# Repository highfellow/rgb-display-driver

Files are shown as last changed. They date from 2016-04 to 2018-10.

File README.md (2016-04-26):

rgb-display-driver
==================

This is a project to make an open hardware display driver for 12v RGB LED strips, with various nice effects including a sound to light mode (colour organ). It is still very much work in progress, so don't expect that it will be usable for any particular purpose at the moment. I've mostly finished designing the electronics and testing them on breadboard, with circuit as shown in the KiCAD schematic. I'm just starting to work on laying out the PCB.

Below are some very rough instructions for compiling the software. I'll put up some better docs soon hopefully.

* The main arduino project is in the `code/` subdirectory.
* The `menu/` subdirectory contains a library which drives the LCD menu system. This needs to be symlinked to the libraries directory of your arduino sketchbook.
* The menu system is currently dependent on the Standard Template Library for Arduino released here: http://andybrown.me.uk/2011/01/15/the-standard-template-library-stl-for-avr-with-c-streams/ . Follow the instructions there to install this. You may need to make the patch described in this comment for it to compile. http://andybrown.me.uk/2011/01/15/the-standard-template-library-stl-for-avr-with-c-streams/#comment-2504271649 . At some point I may well rewrite the library to remove this dependency.

The `pcb/` subdirectory contains a couple of KiCAD projects - one for the main pcb and one for a smaller pcb with the controls attached.

The code files (menu and arduino project) are released under the GPL version 3: http://www.gnu.org/licenses/gpl-3.0.en.html . The KiCAD projects are released under the Creative Commons Attribution-ShareAlike license: http://creativecommons.org/licenses/by-sa/4.0/

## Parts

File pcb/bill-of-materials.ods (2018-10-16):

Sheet: main board bom
Reference Type | Quantity | Reference | Value | Footprint | Datasheet | Manufacturer | Product description | Product code | Supplier | Supplier code | Order | Supplier URL | Tolerance | Type | Notes
C | 1 | C24, | 4.7nF |  |  | Kemet | 4700pF 100V Ceramic Capacitor C0G, NP0 Radial 0.200" L x 0.125" W (5.08mm x 3.18mm) | C320C472J1G5TA | Digikey | 399-4302-ND | No | http://www.digikey.co.uk/product-search/en/capacitors/ceramic-capacitors/131083 | 5% | Ceramic
C | 3 | C22,C16,C14, | 10nF |  |  | Kemet | 10000pF 50V Ceramic Capacitor X7R Radial 0.150" L x 0.100" W (3.81mm x 2.54mm) | C315C103J5R5TA | Digikey | 399-9712-ND | No | http://www.digikey.co.uk/product-detail/en/kemet/C315C103J5R5TA/399-9712-ND/3725975 | 5% | Ceramic
C | 1 | C19, | 47nF |  |  | Kemet | 0.047µF 50V Ceramic Capacitor X7R Radial 0.200" L x 0.125" W (5.08mm x 3.18mm) | C320C473K5R5TA | Digikey | 399-4306-ND | No | http://www.digikey.co.uk/product-detail/en/kemet/C320C473K5R5TA/399-4306-ND/818082 | 10% | Ceramic
C | 8 | C2,C3,C4,C5,C11,C8,C10,C12, | 100nF |  |  | Kemet | 0.10µF 50V Ceramic Capacitor Z5U Radial 0.150" L x 0.100" W (3.81mm x 2.54mm) | C315C104M5U5TA | Digikey | 399-4151-ND | No | http://www.digikey.co.uk/product-detail/en/kemet/C315C104M5U5TA/399-4151-ND/817927 | 20% | Ceramic
C | 6 | C15,C18,C17,C27,C25,C23, | 100nF |  |  | Kemet | 0.10µF 50V Ceramic Capacitor X7R Radial 0.200" L x 0.125" W (5.08mm x 3.18mm) | C320C104J5R5TA | Digikey | 399-9775-ND | No | http://www.digikey.co.uk/product-detail/en/kemet/C320C104J5R5TA/399-9775-ND/3726074 | 10% | Ceramic
C | 2 | C6,C7, | 22pF |  |  | Kemet | 22pF 50V Ceramic Capacitor C0G, NP0 Radial 0.150" L x 0.100" W (3.81mm x 2.54mm) | C315C220J5G5TA | Digikey | 399-9721-ND | No | http://www.digikey.co.uk/product-detail/en/kemet/C315C220J5G5TA/399-9721-ND/3726111 | 20% | Ceramic
C | 3 | C26,C20,C21, | 1uF |  |  | Kemet | 1µF 25V Ceramic Capacitor X7R Radial 0.150" L x 0.100" W (3.81mm x 2.54mm) | C315C105K3R5TA | Digikey | 399-9714-ND | No | http://www.digikey.co.uk/product-search/en/capacitors/ceramic-capacitors/131083 | 10% | Ceramic
C | 3 | C1,C9,C13, | 10uF |  |  | Kemet | 10µF Conformal Coated Tantalum Capacitors 25V Radial 2.5 Ohm 0.217" Dia (5.50mm) | T350E106M025AT | Digikey | 399-9907-ND | No | http://www.digikey.co.uk/product-detail/en/kemet/T350E106M025AT/399-9907-ND/3726214 | 20% | Tantalum
D | 3 | D3,D2,D1, | DIODE-rgb |  |  | Fairchild Semiconductor | Diode Standard 100V 200mA Through Hole DO-35 | 1N4148 | Digikey | 1N4148FS-ND | No | http://www.digikey.co.uk/product-detail/en/fairchild-semiconductor/1N4148/1N4148FS-ND/458603
F | 1 | F1, | FUSE |  |  | Littelfuse Inc. | Fuse Block 15A 600V 1 Circuit Cartridge PCB | 03540101ZXGY | Digikey | F1498-ND | No | http://www.digikey.co.uk/product-detail/en/littelfuse-inc/03540101ZXGY/F1498-ND/553974
IC | 1 | IC1, | ATMEGA328-P | DIL28 |  | Arduino | AT-MEGA 328-P microcontroller | A000048 | Digikey | 1050-1019-ND | No | http://www.digikey.co.uk/product-search/en/integrated-circuits-ics/embedded-microcontrollers/2556109
J | 2 | J6,J7, | AUDIO_JACK |  |  | CUI Inc | 3.50mm (0.141" 1/8" Mini Plug) - Headphone Phone Jack Stereo Connector Solder | SJ1-3523NG | Digikey | CP1-3523NG-ND | No | http://www.digikey.co.uk/product-detail/en/cui-inc/SJ1-3523NG/CP1-3523NG-ND/738692
J | 1 | J4, | CONTROL_HEADER |  |  | On Shore Technology Inc. | 10 Positions Header, Shrouded Connector 0.100" (2.54mm) Through Hole Gold | 302-S101 | Digikey | ED1543-ND | No | http://www.digikey.co.uk/product-detail/en/on-shore-technology-inc/302-S101/ED1543-ND/2178422
J | 1 | J5, | LCD_HEADER |  |  | On Shore Technology Inc. | 14 Positions Header, Shrouded Connector 0.100" (2.54mm) Through Hole Gold | 302-S141 | Digikey | ED10522-ND | No | http://www.digikey.co.uk/product-detail/en/on-shore-technology-inc/302-S141/ED10522-ND/2794233
J | 1 | J2, | LED_CONNECTOR |  |  | CUI Inc. | 6 Position Circular Connector Receptacle, Female Sockets Solder Silver | MD-60S | Digikey | CP-2460-ND | No | http://www.digikey.co.uk/product-detail/en/cui-inc/MD-60S/CP-2460-ND/145311 |  |  | Rated to 2A per conductor at 12V DC
J | 1 | J1, | PWR_IN |  |  | CUI Inc. | Power Barrel Connector Jack 2.50mm ID (0.098"), 5.50mm OD (0.217") Through Hole, Right Angle | PJ-082BH | Digikey UK | CP-082BHCT-ND | No | http://www.digikey.co.uk/product-detail/en/cui-inc/PJ-082BH/CP-082BHCT-ND/3102547
J | 1 | J3, | UART_HEADER |  |  | Phoenix Contact | 5 Position Terminal Block Header, Male Pins, Unshrouded 0.138" (3.50mm) Vertical Through Hole | 1945122 | Digikey | 277-1752-ND | No | http://www.digikey.co.uk/product-detail/en/phoenix-contact/1945122/277-1752-ND/950880
Q | 3 | Q1,Q2,Q3, | IRL510PBF |  |  | Vishay Siliconix | MOSFET N-CH 100V 5.6A TO-220AB | IRL510PBF | Digikey | IRL510PBF-ND | No | http://www.digikey.co.uk/product-detail/en/vishay-siliconix/IRL510PBF/IRL510PBF-ND/811698
Q | 1 | Q4, | TP0606 |  |  | Microchip Technology | MOSFET P-CH 60V 320MA TO92-3 | TP0606N3-G | Digikey | TP0606N3-G-ND | No | http://www.digikey.co.uk/product-detail/en/microchip-technology/TP0606N3-G/TP0606N3-G-ND/4902382
R | 2 | R6,R7, | 1M |  |  | Stackpole Electronics Inc. | RES 1M OHM 1/8W 5% CARBON FILM | CF18JT1M00 | Digikey | CF18JT1M00TR-ND | No | http://www.digikey.co.uk/product-detail/en/stackpole-electronics-inc/CF18JT1M00/CF18JT1M00TR-ND/1741614
R | 1 | R5, | 20R |  |  | Stackpole Electronics Inc. | RES 20 OHM 1/2W 5% CARBON FILM | CF12JT20R0 | Digikey | CF12JT20R0CT-ND | No | http://www.digikey.co.uk/product-detail/en/stackpole-electronics-inc/CF12JT20R0/CF12JT20R0CT-ND/1830451 | 5%
R | 2 | R4,R3, | 20R |  |  | Stackpole Electronics Inc. | METAL FILM 0.125W 5% 22 OHM | CF18JT22R0 | Digikey | CF18JT22R0CT-ND | No | http://www.digikey.co.uk/product-detail/en/stackpole-electronics-inc/CF18JT22R0/CF18JT22R0CT-ND/2022702 | 1%
R | 1 | R2, | 135R |  |  | Stackpole Electronics Inc. | METAL FILM 0.125W 5% 130 OHM | CF18JT130R | Digikey | CF18JT130RCT-ND | No | http://www.digikey.co.uk/product-detail/en/stackpole-electronics-inc/CF18JT130R/CF18JT130RCT-ND/2022721 | 5%
R | 3 | R30,R23,R20, | 180R |  |  | Stackpole Electronics Inc. | RES 180 OHM 1/8W 5% CF AXIAL | CF18JT180R | Digikey | CF18JT180RCT-ND | No | http://www.digikey.co.uk/product-detail/en/stackpole-electronics-inc/CF18JT180R/CF18JT180RCT-ND/2022724
R | 3 | R29,R22,R19, | 2.2k |  |  | Stackpole Electronics Inc. | RES 2.2K OHM 1/8W 5% CF AXIAL | CF18JT2K20 | Digikey | CF18JT2K20CT-ND | No | http://www.digikey.co.uk/product-detail/en/stackpole-electronics-inc/CF18JT2K20/CF18JT2K20CT-ND/2022750
R | 1 | R17, | 3.9k |  |  | Stackpole Electronics Inc. | RES 3.9K OHM 1/8W 5% CARBON FILM | CF18JT3K90 | Digikey | CF18JT3K90CT-ND | No | http://www.digikey.co.uk/product-detail/en/stackpole-electronics-inc/CF18JT3K90/CF18JT3K90CT-ND/2022756
R | 2 | R18,R14, | 8.2k |  |  | Stackpole Electronics Inc. | RES 8.2K OHM 1/8W 5% CF AXIAL | CF18JT8K20 | Digikey | CF18JT8K20CT-ND | No | http://www.digikey.co.uk/product-detail/en/stackpole-electronics-inc/CF18JT8K20/CF18JT8K20CT-ND/2022764
R | 5 | R1,R8,R9,R10,R11, | 10k |  |  | Stackpole Electronics Inc. | RES 10K OHM 1/8W 5% CF AXIAL | CF18JT10K0 | Digikey | CF18JT10K0CT-ND | No | http://www.digikey.co.uk/product-detail/en/stackpole-electronics-inc/CF18JT10K0/CF18JT10K0CT-ND/2022766
R | 5 | R21,R26,R15,R13,R16, | 18k |  |  | Stackpole Electronics Inc. | RES 18K OHM 1/8W 5% CF AXIAL | CF18JT18K0 | Digikey | CF18JT18K0CT-ND | No | http://www.digikey.co.uk/product-search/en/resistors/through-hole-resistors/66690
R | 3 | R31,R25,R24, | 22k |  |  | Stackpole Electronics Inc. | RES 22K OHM 1/8W 5% CF AXIAL | CF18JT22K0 | Digikey | CF18JT22K0CT-ND | No | http://www.digikey.co.uk/product-detail/en/stackpole-electronics-inc/CF18JT22K0/CF18JT22K0CT-ND/2022774
R | 1 | R12, | 33k |  |  | Stackpole Electronics Inc. | RES 33K OHM 1/8W 5% CF AXIAL | CF18JT33K0 | Digikey | CF18JT33K0CT-ND | No | http://www.digikey.co.uk/product-detail/en/stackpole-electronics-inc/CF18JT33K0/CF18JT33K0CT-ND/2022778
R | 3 | R32,R28,R27, | 330k |  |  | Stackpole Electronics Inc. | RES 330K OHM 1/8W 5% CF AXIAL | CF18JT330K | Digikey | CF18JT330KCT-ND | No | http://www.digikey.co.uk/product-detail/en/stackpole-electronics-inc/CF18JT330K/CF18JT330KCT-ND/2022802
RV | 2 | RV3,RV2, | 50R |  |  | Bourns Inc. | 50 Ohm 0.5W, 1/2W PC Pins Through Hole Trimmer Potentiometer Cermet 1 Turn Top Adjustment | 3362P-1-500LF | Digikey | 3362P-1-500LF-ND | No | http://www.digikey.co.uk/product-detail/en/bourns-inc/3362P-1-500LF/3362P-1-500LF-ND/2536639
RV | 2 | RV1,RV4, | 10k |  |  | Bourns Inc. | 10k Ohm 0.5W, 1/2W PC Pins Through Hole Trimmer Potentiometer Cermet 1 Turn Top Adjustment | 3362P-1-103LF | Digikey | 3362P-103LF-ND | No | http://www.digikey.co.uk/product-detail/en/bourns-inc/3362P-1-103LF/3362P-103LF-ND/1088412
SW | 1 | SW1, | SW_POWER |  |  | C&K Components | Rocker Switch SPDT 7.5A (AC/DC) 125V Through Hole, Right Angle | E101J1AQE2 | Digikey | CKN2070-ND | No | http://www.digikey.co.uk/product-detail/en/c-k-components/E101J1AQE2/CKN2070-ND/484024
U | 4 | U2,U3,U5,U4, | LM358_BIG |  |  | Texas Instruments | General Purpose Amplifier 2 Circuit 8-PDIP | LM358P | Digikey | 296-1395-5-ND | No | http://www.digikey.co.uk/product-detail/en/texas-instruments/LM358P/296-1395-5-ND/277042
U | 1 | U1, | 7805_NUM |  |  | ON Semiconductor | Linear Voltage Regulator IC Positive Fixed 1 Output 5V 1A TO-220AB | NCP7805TG | Digikey | NCP7805TGOS-ND | No | http://www.digikey.co.uk/product-detail/en/on-semiconductor/NCP7805TG/NCP7805TGOS-ND/2271529
X | 1 | X1, | 16MHz |  |  | TXC CORPORATION | 16MHz ±10ppm Crystal 18pF 30 Ohm -20°C ~ 70°C Through Hole HC49/US | 9B-16.000MEEJ-B | Digikey | 887-1244-ND | No | http://www.digikey.co.uk/product-detail/en/txc-corporation/9B-16.000MEEJ-B/887-1244-ND/2207664

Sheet: controls board bom
Reference Type | Quantity | Reference | Value | Footprint | Datasheet | Manufacturer | Product description | Product code | Supplier | Supplier code | Order | Supplier URL
D | 1 | D1, | LED_RABG |  |  | Adafruit Industries LLC | Red, Green, Blue (RGB) LED Indication - Discrete 2.1V Red, 3.8V Green, 2.7V Blue 4-DIP (0.200" 5.08mm) | 314 | Digikey | 1528-1127-ND | No | http://www.digikey.co.uk/product-detail/en/adafruit-industries-llc/314/1528-1127-ND/5353587
J | 1 | J1, | CONTROLS_HEADER |  |  | On Shore Technology Inc. | 10 Positions Header, Shrouded Connector 0.100" (2.54mm) Through Hole Gold | 302-S101 | Digikey | ED1543-ND | No | http://www.digikey.co.uk/product-detail/en/on-shore-technology-inc/302-S101/ED1543-ND/2178422
J | 1 | J2, | ENCODER |  |  | TT Electronics/BI | ENCODER 12MM ROTARY TOP ADJUST | EN12-HN22AF25 | Digikey | 987-1399-ND | No | http://www.digikey.co.uk/product-detail/en/tt-electronics-bi/EN12-HN22AF25/987-1399-ND/2620668
SW | 1 | SW2, | MODE BUTTON |  |  | C&K Components | Pushbutton Switch SPST-NO Keyswitch Through Hole | D6R40 F1 LFS | Digikey | 401-1975-ND | No | http://www.digikey.co.uk/product-detail/en/c-k-components/D6R40-F1-LFS/401-1975-ND/1466332
SW | 1 | SW1, | PARAM BUTTON |  |  | C&K Components | Pushbutton Switch SPST-NO Keyswitch Through Hole | D6R50 F1 LFS | Digikey | 401-1976-ND | No | http://www.digikey.co.uk/product-detail/en/c-k-components/D6R50-F1-LFS/401-1976-ND/1466333

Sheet: extra parts
Extra parts – i.e. parts not on PCB but needed for assembly
Description | Quantity | Manufacturer | Product Code | Supplier | Supplier Code | URL
FUSE GLASS 7.5A 32VAC/VDC 3AB | 1 | Littelfuse Inc. | 0AGC07.5V | Digikey | F5024-ND | http://www.digikey.co.uk/product-detail/en/littelfuse-inc/0AGC07.5V/F5024-ND/2519098
6 Position Circular Connector Plug, Male Pins Solder, Crimp Pin Adapter Available Silver | 2 | CUI Inc. | MD-60 | Digikey | CP-2060-ND | http://www.digikey.co.uk/product-detail/en/cui-inc/MD-60/CP-2060-ND/96916
10 Position Rectangular Socket Connector IDC Gold | 2 | On Shore Technology Inc. | 101-106 | Digikey | ED10500-ND | http://www.digikey.co.uk/product-detail/en/on-shore-technology-inc/101-106/ED10500-ND/2794212
14 Position Rectangular Socket Connector IDC Gold | 1 | On Shore Technology Inc. | 101-146 | Digikey | ED10501-ND | http://www.digikey.co.uk/product-detail/en/on-shore-technology-inc/101-146/ED10501-ND/2794213
KNOB KNURLED 0.750" METAL | 1 | Kilo International | OEJNI-75-4-7 | Digikey | 226-4239-ND | http://www.digikey.co.uk/product-detail/en/kilo-international/OEJNI-75-4-7/226-4239-ND/5970395
Flat Ribbon Cable Gray 14 Conductors 0.050" (1.27mm) Flat Cable 5.0' (1.52m) | 1 | 3M | 3365/14 300SF | Digikey | MC14G-5-ND | http://www.digikey.co.uk/product-detail/en/assmann-wsw-components/AWG28-14-G-300/AE14G-5-ND/686330
6 Position Circular Connector Receptacle, Female Sockets Solder Silver | 2 | CUI Inc. | MD-60SV | Digikey | CP-2760-ND | http://www.digikey.co.uk/product-detail/en/cui-inc/MD-60SV/CP-2760-ND/299895
12V 84W AC/DC External Desktop (Class I) Adapter Cord (Sold Separately) Input | 1 | Volgen America/Kaga Electronics USA | KTPS90-1207 | Digikey | 62-1186-ND | http://www.digikey.co.uk/product-detail/en/volgen-america-kaga-electronics-usa/KTPS90-1207/62-1186-ND/3024981

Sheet: old-bom
 | Value | Quantity | Refs | From (CPC / Farnell / Have) | Code
Main Board | 22pF | 2 | C6 C7 | Have | -
 | 4.7nF | 1 | C25 | Farnell | 1100379
 | 10nF | 3 | C13 C16 C24 | Farnell | 2332955
 | 47nF | 1 | C17 | Farnell | 1457648
 | 100nF | 13 | C2 C3 C4 C5 C8 C9 C10 C11 C14 C15 C18 C19 C26 | Farnell | 2112751
 | 1uF | 5 | C21 C22 C23 C27 C28 | Farnell
 | 10uF | 3 | C1 C12 C20 | Farnell
 | DIODE | 3 | D1 D2 D3 | Farnell | 1700925
 | ATMEGA328-P | 1 | IC1 | Have | -
 | LED_HEADER | 1 | J2 | Farnell | 1593440
 | LCD_HEADER | 1 | J4 | Farnell | 1593429
 | CONTROL_HEADER | 1 | J5 | Farnell | 1593429
 | AUDIO_HEADER_OUT | 1 | J6 | Farnell | 1593412
 | AUDIO_HEADER_IN | 1 | J7 | Farnell | 1593412
 | PWR_IN | 1 | J1 | Farnell | 1593413
 | UART_HEADER | 1 | J3 | Farnell | 1593414
 | STP35NF10 | 3 | Q1 Q2 Q3 | Have | -
 | 3.9k | 2 | R10 R13 | Farnell | 9343156
 | 6.8k | 3 | R17 R18 R24 | Farnell | 9343466
 | 8.2k | 2 | R12 R14 | Farnell | 9343571
 | 10k | 7 | R1 R4 R5 R6 R7 | Farnell | 9342419
 | 15k | 4 | R9 R11 R19 R20 | Farnell | 9342630
 | 33k | 3 | R8 R22 R25 | Farnell | 9343059
 | 100k | 4 | R15 R16 R21 R23 | Farnell | 9342427
 | 1M | 2 | R2 R3 | Farnell | 9342435
 | 10k | 2 | RV1 RV2 | Farnell | 1227539
 | SW_POWER | 1 | SW1 | Farnell | 1437701
 | SW_PUSH | 1 | SW2 | Have | -
 | 7805 | 1 | U1 | Have | -
 | LM358 | 4 | U2 U3 U4 U5 | Farnell | 1211132
 | 16MHz | 1 | X1 | Have | -
Controls Board | CONTROLS_HEADER | 1 | J1 | Farnell | 1593429
 | ENCODER | 1 | J2
 | PARAM BUTTON | 1 | SW1
 | MODE BUTTON | 1 | SW2
Misc | DIP-28 socket | 1
 | Ribbon cable | 1 metre
 | 3x2 header socket | 3 |  | Farnell | 1593488
 | 3x1 header socket | 2 |  | Farnell | 1593459
 | 4x1 header socket | 1 |  | Farnell | 1593460
 | 5x1 header socket | 1 |  | Farnell | 1593461
 | 2.5mm screws | 100 |  | Farnell | 1420119

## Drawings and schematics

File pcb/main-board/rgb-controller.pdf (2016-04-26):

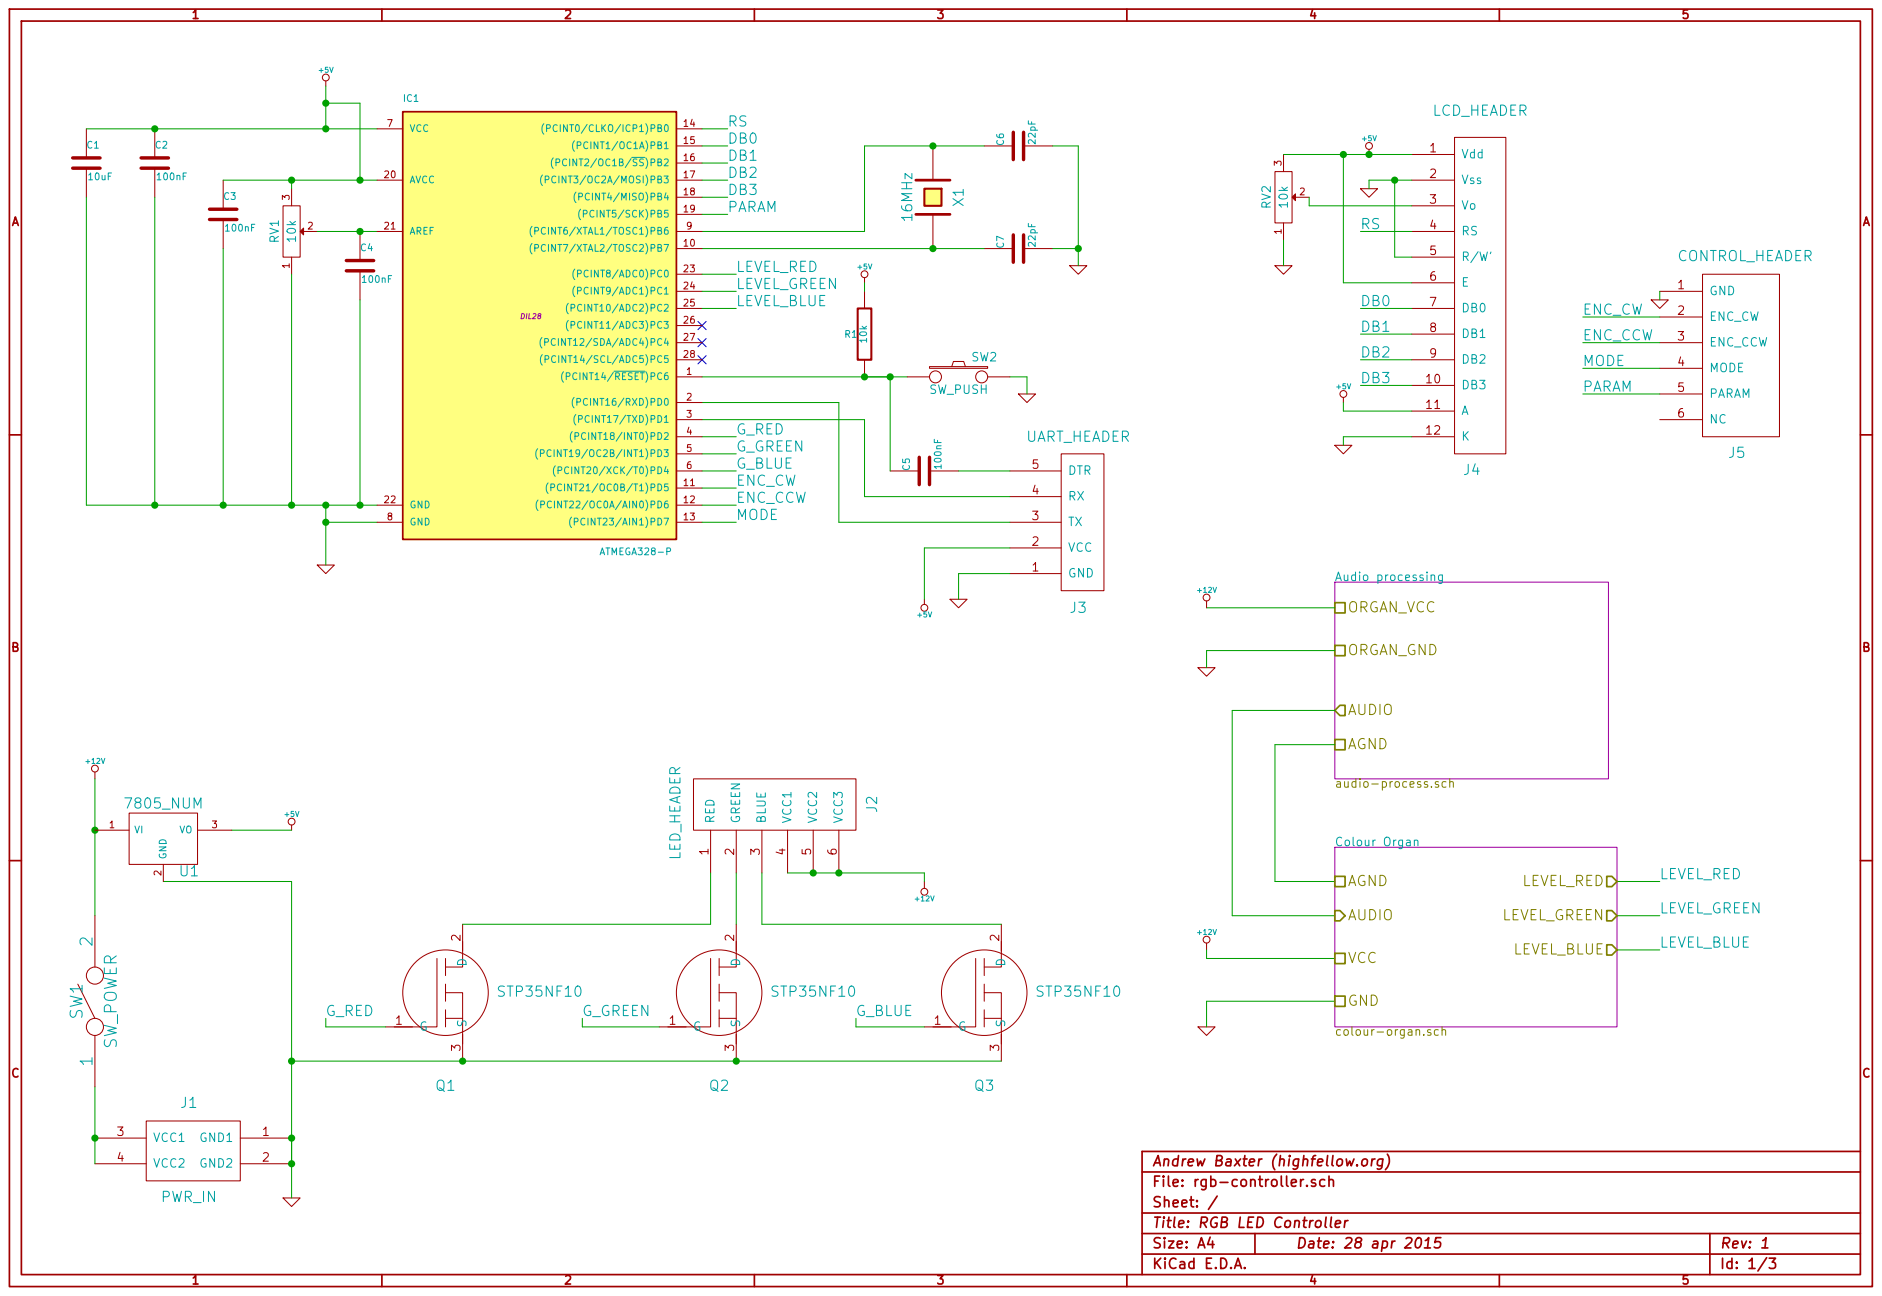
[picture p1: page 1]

File: rgb-controller.sch
Sheet: /
Title: RGB LED Controller
KiCad E.D.A.

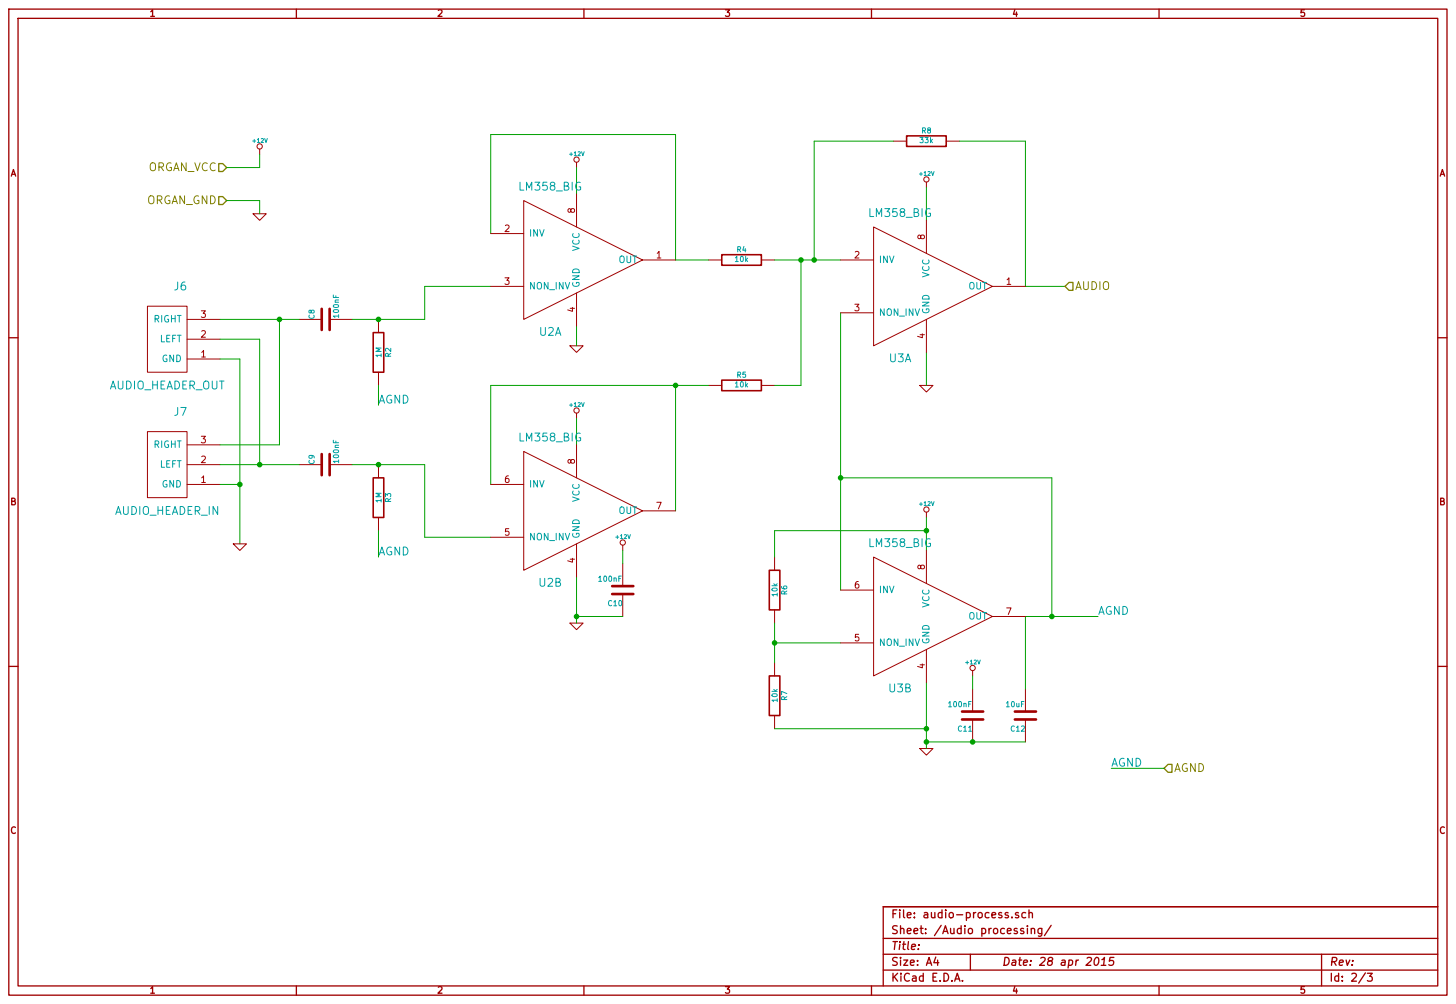
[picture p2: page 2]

Id: 2/3 Title: File: audio-process.sch
Sheet: /Audio processing/

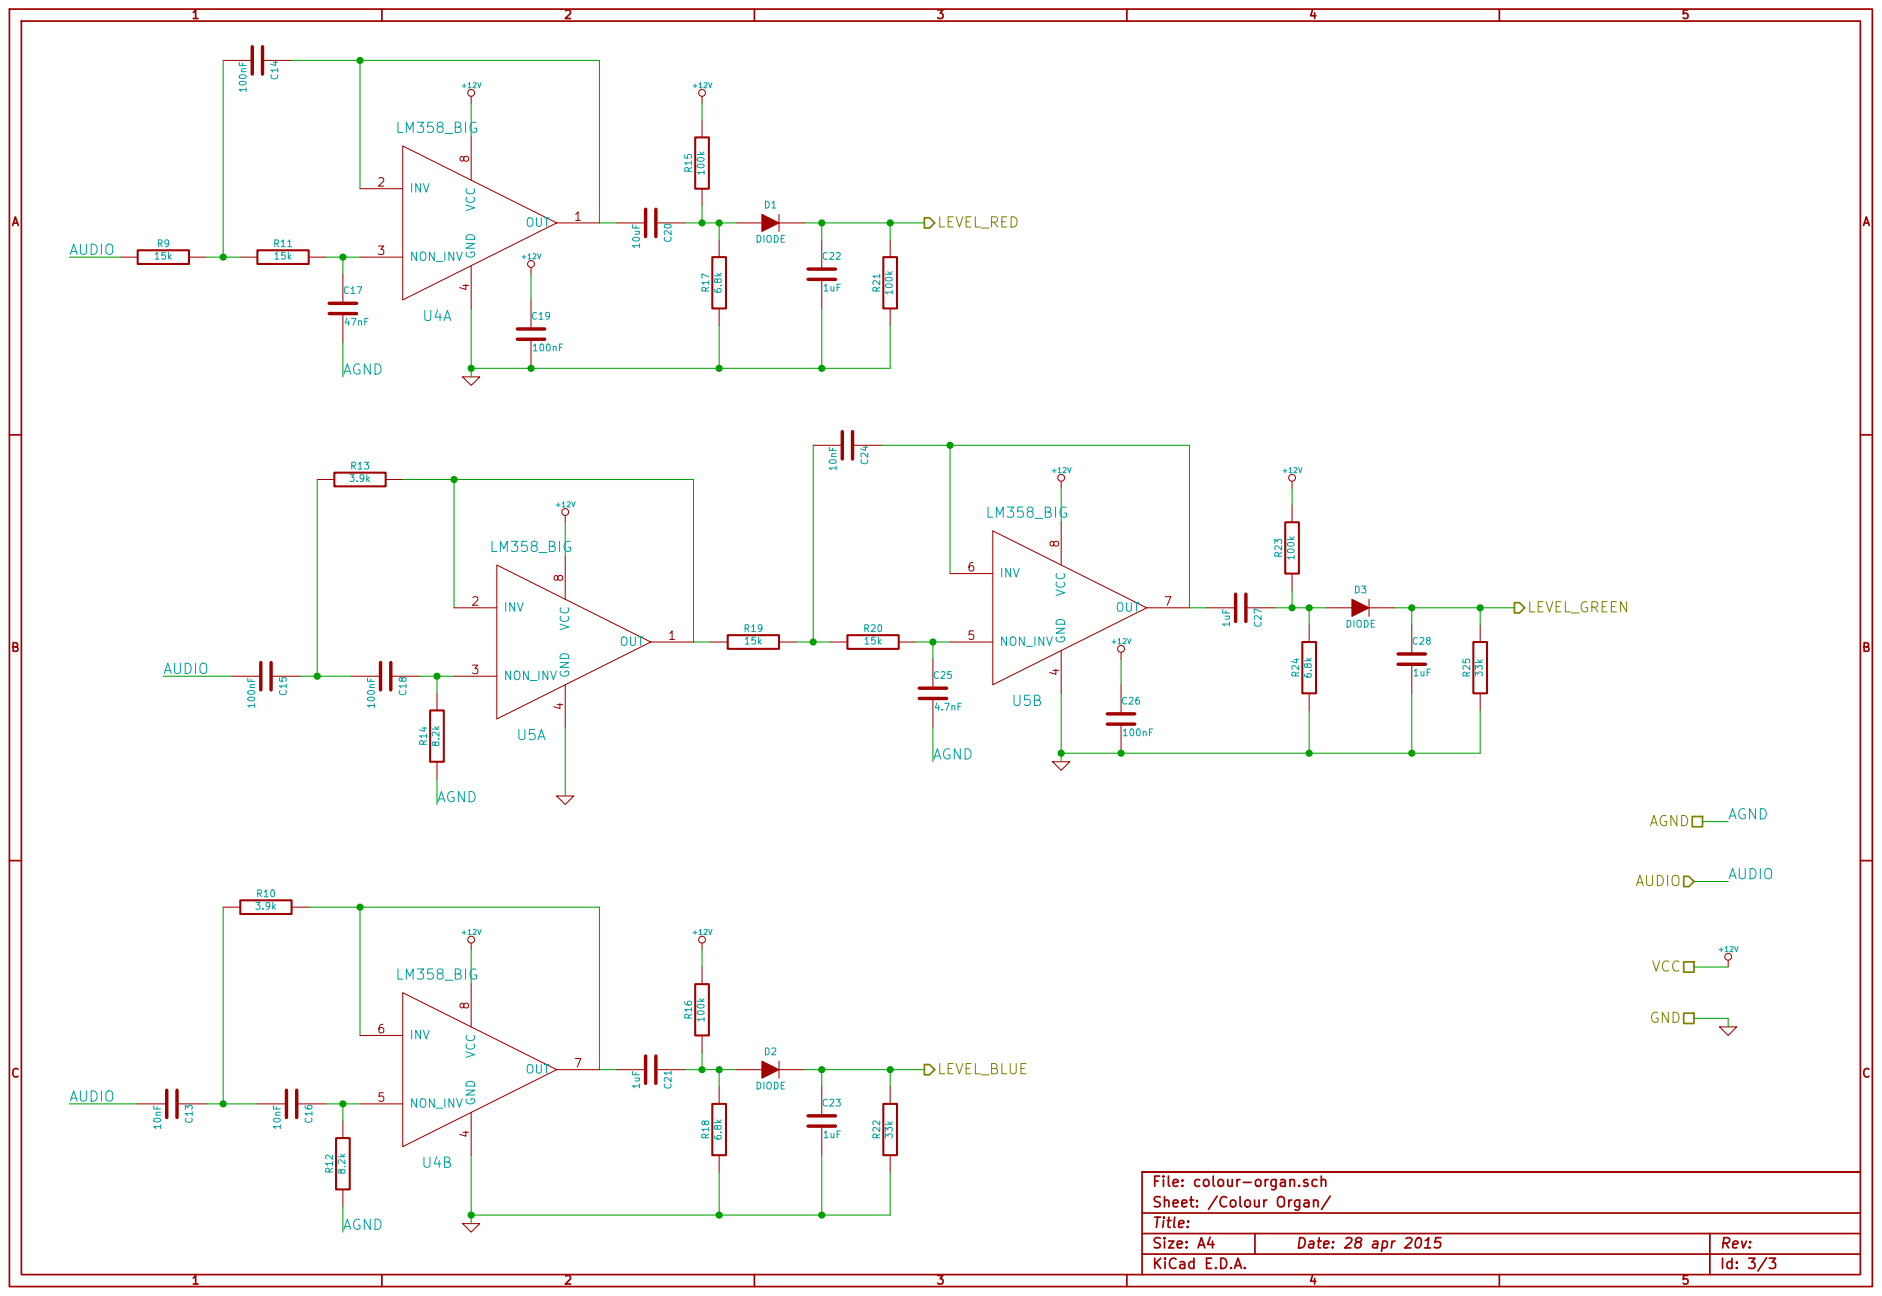
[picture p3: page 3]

Id: 3/3 Title: File: colour-organ.sch
Sheet: /Colour Organ/

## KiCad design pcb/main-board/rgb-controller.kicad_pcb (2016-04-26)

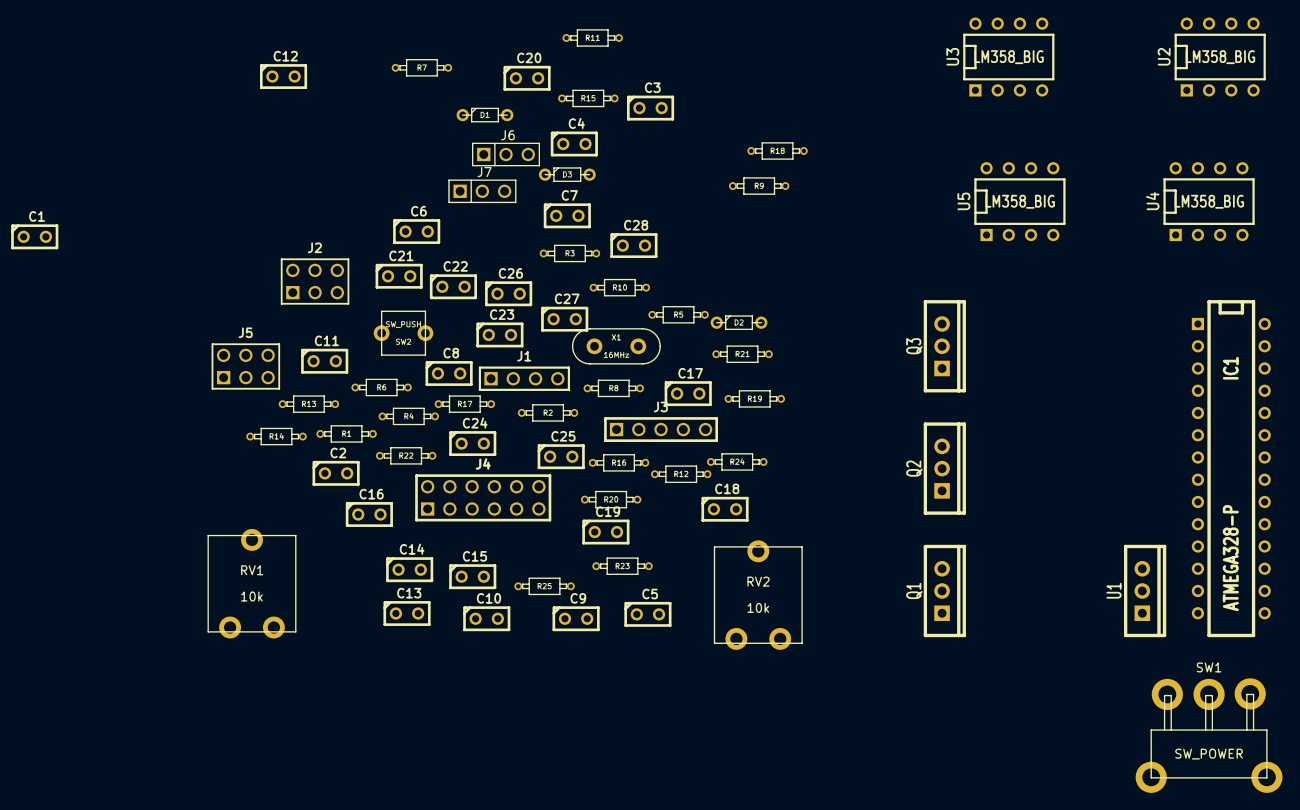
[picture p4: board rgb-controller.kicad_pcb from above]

Board: 2 copper layers, 77 parts (0 on the bottom side), 55 nets, no tracks yet.

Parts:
C1, C12, C20: 10uF; C1
C2, C3, C4, C5, C8, C9, C10, C11, C14, C15, C18, C19, C26: 100nF; C1
C6, C7: 22pF; C1
C13, C16, C24: 10nF; C1
C17: 47nF; C1
C21, C22, C23, C27, C28: 1uF; C1
C25: 4.7nF; C1
D1, D2, D3: DIODE; D2
IC1: ATMEGA328-P; DIP-28__300
J1: PWR_IN; PIN_ARRAY_4x1
J2: LED_HEADER; pin_array_3x2
J3: UART_HEADER; PIN_ARRAY_5x1
J4: LCD_HEADER; pin_array_6x2
J5: CONTROL_HEADER; pin_array_3x2
J6: AUDIO_HEADER_OUT; PIN_ARRAY_3X1
J7: AUDIO_HEADER_IN; PIN_ARRAY_3X1
Q1, Q2, Q3: STP35NF10; TO220_NUM
R1, R4, R5, R6, R7: 10k; R_MF12
R2, R3: 1M; R_MF12
R8, R22, R25: 33k; R_MF12
R9, R11, R19, R20: 15k; R_MF12
R10, R13: 3.9k; R_MF12
R12, R14: 8.2k; R_MF12
R15, R16, R21, R23: 100k; R_MF12
R17, R18, R24: 6.8k; R_MF12
RV1, RV2: 10k; RV_CB10
SW1: SW_POWER; SW_1101
SW2: SW_PUSH; SW_TACT
U1: 7805_NUM; TO220_NUM
U2, U3, U4, U5: LM358_BIG; DIP-8__300
X1: 16MHz; XTAL_16

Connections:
+5V: C1.1, C2.1, C3.1, IC1.7, IC1.20, J3.2, J4.1, J4.6, J4.11, R1.2, RV1.3, RV2.3, U1.3
+12V: C10.2, C11.2, C19.1, C26.1, J2.4, J2.5, J2.6, R6.1, R15.2, R16.2, R23.2, SW1.2, U1.1, U2.8, U3.8, U4.8, U5.8
/Audio processing/AGND: C12.2, C17.2, C25.2, R2.2, R3.2, R12.1, R14.1, U3.3, U3.6, U3.7
/Audio processing/AUDIO: C13.2, C15.2, R8.2, R9.1, U3.1
/Colour Organ/LEVEL_BLUE: C23.1, D2.2, IC1.25, R22.2
/Colour Organ/LEVEL_GREEN: C28.1, D3.2, IC1.24, R25.2
/Colour Organ/LEVEL_RED: C22.1, D1.2, IC1.23, R21.2
/DB0: IC1.15, J4.7
/DB1: IC1.16, J4.8
/DB2: IC1.17, J4.9
/DB3: IC1.18, J4.10
/ENC_CCW: IC1.12, J5.3
/ENC_CW: IC1.11, J5.2
/G_BLUE: IC1.6, Q3.1
/G_GREEN: IC1.5, Q2.1
/G_RED: IC1.4, Q1.1
/MODE: IC1.13, J5.4
/PARAM: IC1.19, J5.5
/RS: IC1.14, J4.4
GND: C1.2, C2.2, C3.2, C4.2, C6.2, C7.2, C10.1, C11.1, C12.1, C19.2, C22.2, C23.2, C26.2, C28.2, IC1.8, IC1.22, J1.1, J1.2, J3.1, J4.2, J4.5, J4.12, J5.1, J6.1, J7.1, Q1.3, Q2.3, Q3.3, R7.2, R17.1, R18.1, R21.1, R22.1, R24.1, R25.1, RV1.1, RV2.1, SW2.2, U1.2, U2.4, U3.4, U4.4, U5.4
unnamed: IC1.3, J3.4
unnamed: IC1.2, J3.3
unnamed: J4.3, RV2.2
unnamed: J2.1, Q1.2
unnamed: J2.2, Q2.2
unnamed: C5.1, IC1.1, R1.1, SW2.1
unnamed: J2.3, Q3.2
unnamed: C5.2, J3.5
unnamed: J1.3, J1.4, SW1.1
unnamed: C7.1, IC1.10, X1.2
unnamed: C6.1, IC1.9, X1.1
unnamed: C4.1, IC1.21, RV1.2
unnamed: R4.2, R5.2, R8.1, U3.2
unnamed: R5.1, U2.6, U2.7
unnamed: C9.1, J6.2, J7.2
unnamed: C8.1, J6.3, J7.3
unnamed: R4.1, U2.1, U2.2
unnamed: R6.2, R7.1, U3.5
unnamed: C8.2, R2.1, U2.3
unnamed: C9.2, R3.1, U2.5
unnamed: C25.1, R20.2, U5.5
unnamed: C18.1, R14.2, U5.3
unnamed: R13.2, R19.1, U5.1, U5.2
unnamed: C24.2, R19.2, R20.1
unnamed: C27.1, D3.1, R23.1, R24.2
unnamed: C16.1, R12.2, U4.5
unnamed: C15.1, C18.2, R13.1
unnamed: C14.1, C20.2, U4.1, U4.2
unnamed: C21.2, R10.2, U4.6, U4.7
unnamed: C24.1, C27.2, U5.6, U5.7
unnamed: C13.1, C16.2, R10.1
unnamed: C20.1, D1.1, R15.1, R17.2
unnamed: C21.1, D2.1, R16.1, R18.2
unnamed: C17.1, R11.2, U4.3
unnamed: C14.2, R9.2, R11.1

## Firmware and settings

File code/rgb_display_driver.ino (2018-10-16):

// sketch to drive rgb LED ribbon


// Uses clock in normal mode (no PWM)

// include the library code:
#include <avr/interrupt.h>
#include <avr/pgmspace.h>
#include <math.h>
#include <LiquidCrystal.h>
#include <Rotary.h>
#include <LcdMenu.h>

#define UNITY 4096 // fixed point unity value.
#define UNITY_BITS 12 // same expressed as a power of 2.
#define UNITY_SQR ((int32_t)1 << (UNITY_BITS * 2)) // unity squared.
#define IN_POINTS 2 // binary points to add to input values.
#define OUT_POINTS 4 // binary points to remove from output values.
#define ROTARY_PIN_1 12 // first pin for rotary encoder
#define ROTARY_PIN_2 13 // second pin for rotary encoder
#define OUT_PORT PORTD // port to use for PWM output.
#define OUT_DDR DDRD // data direction register for given port.
#define OUT_BASE 4 // offset of first PWM pin in given port.
#define CHAN_BASE 2 // analog pin of first frequency channel
#define MODES 4 // number of driver modes.
#define MAX_TIME 15000 // maximum fade time in 30000ths of a second
#define LEVEL_SAMPS 300000 // samples to average level over.
#define DECAY_MAX 4084 // max and min decay ratios for audio channels
#define DECAY_MIN 2048 // in units of UNITY
#define CHAN_MIN 100 // min values of channels decay towards this
                     // value over approx 5 mins
#define CHAN_SEP 200 // minimum separation between min and max
                    // channel values
#define MINMAX_DECAY 4086 // decay ratio with 5 min half life when done every second.
#define RAN_SMOOTH 256 // used when smoothing colour fade to stop flicker.
#define RAN_SPEED 500 // maximum colour fade speed.
#define ENABLE_PULLUPS // for the rotary library.
#define FLICKER_BASE_SINGLE 3 // base of flicker params for single 
  // colour mode
#define FLICKER_BASE_FADE 2 // ditto for colour fade
#define FLICKER_BASE_RATE 2 // number of base time steps in one
  // fast flicker.


// clock rate: 15.625kHz
// refresh rate: ~61.0Hz
// analog read rate: ~244Hz

// defines for the meanings of the channels in non-RGB colour mode.
// RGB mode:
#define CHAN_RED 0 // red channel
#define CHAN_GREEN 1 // green channel
#define CHAN_BLUE 2 // blue channel
// HSV mode:
#define PARM_VALUE 0 // hsv value
#define PARM_SAT 1 // hsv saturation
#define PARM_HUE 2 // hsv hue
// Colour fade mode:
#define PARM_SPEED 1 // colour cycle speed.
// Colour organ mode:
#define PARM_DECAY 1 // speed of change under peak level.
#define PARM_PEAKY 2 // ratio of peaks to whole signal.
// Flicker modes
#define PARM_FL_SPEED 0 // flicker speed
#define PARM_FL_FADE 1 // flicker fading
#define PARM_FL_DEPTH 2 // flicker depth

volatile int16_t out[] = {0, 0, 0}; // rgb output value.
volatile int16_t count = 0; // PWM count.
volatile unsigned char adcChan = 0; // adc channel
volatile int16_t chanVals[3]; // values from audio filter channels.
char mode = 1; // colour changing mode.
volatile char doLoop = false;
LcdMenu *menu;
LiquidCrystal *lcd;
Rotary *rot;

ISR(TIMER2_COMPA_vect) {
  // Interrupt service routine for timer 2 overflow.
  //PORTB |= 1 << DIAG_PIN - 8;
  uint8_t mask = 1 << OUT_BASE;
  count++;
  for (int16_t chan = 0; chan < 3; chan++) {
    if (count < out[chan]) {
      OUT_PORT |= mask; // turn pin on.
      } else {
      OUT_PORT &= ~(mask); // turn pin off.
    }
    mask <<= 1;
  }
  // this expression looks ugly but mostly should be evaluated at compile time.
  if ((count & (0xffff >> (16 - UNITY_BITS + OUT_POINTS + 2))) == 0) {
    // do ADC stuff.
    /*if (adcChan > 0) {
      // read result.
      chanVals[adcChan - 1] = ADCL | (ADCH << 8);
    }
    if (adcChan < 3) {
      // start conversion.
      ADMUX = adcChan; // set channel.
      ADCSRA |= _BV(ADSC); // start conversion.
    }
    adcChan++;
    adcChan &= 0b11;*/ // count from 0 to 3;
    doLoop = true; // tell the main loop to run again.
  }
  if (count >= (UNITY >> OUT_POINTS)) {
    //doLoop = true; // tell the main loop to run again.
    count = 0;
  }
  //PORTB &= ~(1 << DIAG_PIN - 8);
}

void encoderInterrupt() {
  menu->readEncoder();
}

void getModeVals(MenuMode *mode, int16_t *parms, char offset, 
  char count) {
  // get first <count> values from current mode into an array.
  MenuParamList *params;
  params = mode->getParams();
  for (unsigned char i = offset; i < offset + count; i++) {
    parms[i - offset] = (((int64_t)params->get(i)->getValue()->get() * 1023) / 1000) << IN_POINTS;
  }
}

uint32_t intExp(uint32_t power) {
  // returns 2 ^ power (approx.)
  uint8_t prevPower;
  uint8_t nextPower;
  uint32_t rem;
  uint32_t ret;
  prevPower = power >> UNITY_BITS;
  nextPower = prevPower + 1;
  rem = power % UNITY;
  ret = ((UNITY - rem) << prevPower) + (rem << nextPower);
  return ret;
}

void setOutput(int16_t vals[3]) {
  int16_t val;
  for (int16_t chan = 0; chan < 3; chan++) {
    val = vals[chan];
    if (val < 0) val = 0;
    if (val > UNITY - 1) val = UNITY - 1;
    out[chan] = val >> OUT_POINTS;
  }
}

uint8_t lsfrBit() {
  static uint16_t lfsr = 1; // 16 bit linear feedback shift register
  uint16_t newBit;
  newBit = ((lfsr >> 0) ^ (lfsr >> 2) ^ (lfsr >> 3) ^ 
    (lfsr >> 5) ) & 1;
  lfsr =  (lfsr >> 1) | (newBit << 15);
  return newBit;
}

int16_t addFlicker(MenuMode *mode, unsigned char parmBase) {
  static int32_t bright = UNITY_SQR - 1; // brightness
  static uint32_t flickerAcc = 0, fadeAcc = 0; // accumulators for
    // flicker and fading.
  static int32_t target = UNITY_SQR - 1; // target  brightness.
  int16_t parms[3];
  uint32_t rate, fadeRate;
  getModeVals(mode, parms, parmBase + 1, 3);
  rate = intExp( ((uint32_t)parms[PARM_FL_SPEED] * 6 + 
    4 * UNITY)) >> UNITY_BITS; // should go from 16 to 1024.
  fadeRate = rate * (intExp( (uint32_t)12 * UNITY -
    (uint32_t)parms[PARM_FL_FADE] * 8) >> UNITY_BITS);
    // should go from rate * 16 to rate * 4096
  flickerAcc += rate;
  fadeAcc += fadeRate;
  if (flickerAcc >= FLICKER_BASE_RATE * 1024) {
    flickerAcc -= FLICKER_BASE_RATE * 1024;
    if (lsfrBit() == 1) {
      target = UNITY_SQR - 1;
    } else {
      target = UNITY_SQR - 1 - 
        UNITY * (int32_t)parms[PARM_FL_DEPTH];
    }
  }
  if (fadeAcc >= FLICKER_BASE_RATE * 1024) {
    uint16_t compress = fadeAcc / (FLICKER_BASE_RATE * 1024);
    if (compress > 256) compress = 256;
    fadeAcc %= FLICKER_BASE_RATE * 1024;
    bright += (target - bright) * compress / 256;
  }
  return bright >> UNITY_BITS;
}

void colourOrgan(MenuMode *mode) {
  static int16_t chanMins[] = {UNITY, UNITY, UNITY};
    // minimum levels on channels
  static int16_t chanMaxes[] = {CHAN_SEP, CHAN_SEP, CHAN_SEP};
    // maximum levels on channels
  static int16_t chanBases[] = {0, 0, 0};
    // levels of base (non-peak) parts of channels.
  static char second = 0;
  int16_t parms[3];
  int16_t decay, peaky, bright;
  getModeVals(mode, parms, 0, 3);
  decay = intExp( (uint32_t)(UNITY - parms[PARM_DECAY]) * 10) >> 10;
  decay = DECAY_MAX - (((DECAY_MAX - DECAY_MIN) * (int64_t) decay)
    >> UNITY_BITS);
  // separate into fast peak part and smoothed base value.
  peaky = parms[PARM_PEAKY];
  bright = intExp((uint32_t) parms[PARM_VALUE] * 10) >> 10;
  second++;
  if (second == 61) second = 0;
  for (char chan = 0; chan < 3; chan++) {
    int16_t val = chanVals[chan];
    int16_t peakVal, baseVal;
    // make min and max levels decay towards CHAN_MIN with a 5 minute half life.
    if (second == 0) {
      chanMins[chan] = CHAN_MIN + 
        ((((int64_t) chanMins[chan] - CHAN_MIN) * MINMAX_DECAY)
        >> UNITY_BITS);
      chanMaxes[chan] = chanMins[chan] + CHAN_SEP +
        ((((int64_t) chanMaxes[chan] - chanMins[chan] - CHAN_SEP)
        * MINMAX_DECAY) >> UNITY_BITS);
    }
    if (val < chanMins[chan]) chanMins[chan] = val;
    if ((val > chanMins[chan] + CHAN_SEP) && 
      (val > chanMaxes[chan])) chanMaxes[chan] = val;
    val = ( ((int64_t) val - (int64_t) chanMins[chan]) << UNITY_BITS) /
      (chanMaxes[chan] - chanMins[chan]);
    peakVal = ((int64_t) val * (int64_t) peaky) >> UNITY_BITS;
    baseVal = ((int64_t) val * (UNITY - (int64_t) peaky)) >> UNITY_BITS;
    baseVal = (((int64_t) baseVal * (UNITY - (int64_t) decay)) + 
              ((int64_t) chanBases[chan] * (int64_t) decay)) >> UNITY_BITS;
    chanBases[chan] = baseVal;
    val = (((int64_t) peakVal + (int64_t) baseVal) * ((int64_t) bright)) >> UNITY_BITS;
    parms[chan] = intExp((uint32_t) val * 6) >> 6;
  }
  setOutput(parms);
}

void setHSV(MenuMode *mode) {
  // hsv to rgb from wikipedia algorithm.
  int16_t parms[3];
  int64_t c;
  int64_t x;
  int16_t h_;
  int16_t hmod;
  int64_t m;
  getModeVals(mode, parms, 0, 3);
  parms[PARM_VALUE] = intExp((uint16_t) parms[PARM_VALUE] * 7) >> 7;
  parms[PARM_VALUE] = ((int32_t)parms[PARM_VALUE] * 
    addFlicker(mode, FLICKER_BASE_SINGLE)) >> UNITY_BITS;
  c = ((int64_t) parms[PARM_VALUE] * (int64_t) parms[PARM_SAT]) >> UNITY_BITS;
  h_ = parms[PARM_HUE] * 6;
  hmod = h_ % (UNITY << 1) - UNITY;
  if (hmod < 0) hmod = -hmod;
  x = (c * (UNITY - (int64_t) hmod)) >> UNITY_BITS;
  m = parms[PARM_VALUE] - c;
  switch (h_ >> UNITY_BITS) {
    case 0:
      parms[CHAN_RED] = c + m;
      parms[CHAN_GREEN] = x + m;
      parms[CHAN_BLUE] = m;
      break;
    case 1:
      parms[CHAN_RED] = x + m;
      parms[CHAN_GREEN] = c + m;
      parms[CHAN_BLUE] = m;
      break;
    case 2:
      parms[CHAN_RED] = m;
      parms[CHAN_GREEN] = c + m;
      parms[CHAN_BLUE] = x + m;
      break;
    case 3:
      parms[CHAN_RED] = m;
      parms[CHAN_GREEN] = x + m;
      parms[CHAN_BLUE] = c + m;
      break;
    case 4:
      parms[CHAN_RED] = x + m;
      parms[CHAN_GREEN] = m;
      parms[CHAN_BLUE] = c + m;
      break;
    case 5:
      parms[CHAN_RED] = c + m;
      parms[CHAN_GREEN] = m;
      parms[CHAN_BLUE] = x + m;
      break;
  }
  setOutput(parms);
}

void colourCycle(MenuMode *mode) {
  static int16_t rgb[] = {UNITY, UNITY, UNITY}, smoothed[] = {UNITY, UNITY, UNITY};
  int16_t parms[2], outVals[3]; 
  int16_t delta, maxVal, abVal, norm, smooth;
  char maxChan;
  getModeVals(mode, parms, 0, 2); // brightness, saturation, speed.
  parms[PARM_VALUE] = intExp((uint16_t) parms[PARM_VALUE] * 7) >> 7;
  parms[PARM_VALUE] = ((int32_t)parms[PARM_VALUE] * 
    addFlicker(mode, FLICKER_BASE_FADE)) >> UNITY_BITS;
  parms[PARM_SPEED] = intExp((uint16_t) parms[PARM_SPEED] * 4) >> 4;
  delta = ((int64_t)parms[PARM_SPEED] * RAN_SPEED) >> UNITY_BITS;
  if (delta < 1) delta = 1;
  maxVal = 0;
  maxChan = -1;
  // add random delta and find max coord.
  for (char i = 0; i < 3; i++) {
    rgb[i] += random(-delta, delta); 
    abVal = abs(rgb[i]);
    if (abVal > maxVal) {
      maxVal = abVal;
      maxChan = i;
    }
  }
  // renormalise onto surface of unit cube.
  norm = ((int64_t)UNITY << UNITY_BITS) / maxVal;
  for (char i = 0; i < 3; i++) {
    rgb[i] = ( (int64_t)rgb[i] * norm) >> UNITY_BITS;
    // set output values. (smoothed to stop flicker at high speeds).
    smoothed[i] = ( ( ( (int64_t)smoothed[i] * (UNITY - RAN_SMOOTH) ) +
      ( (int64_t)abs(rgb[i]) * RAN_SMOOTH) ) )  >> UNITY_BITS;
    outVals[i] = ( (int64_t)smoothed[i] * parms[PARM_VALUE] ) >> UNITY_BITS;
  }
  setOutput(outVals);  
}

void addFlickerModes(MenuParamList *params, unsigned char parmBase) {
  MenuParam *param;
  MenuParamValue *value;
  value = new MenuParamValueOption(0, 2);
  value->setOption(0, F("off  "));
  value->setOption(1, F("on   "));
  param = new MenuParam(F("Flicker    "), value);
  params->set(parmBase, param);
  value = new MenuParamValuePercent(500);
  param = new MenuParam(F("Fl. speed  "), value);
  params->set(parmBase + 1, param);
  value = new MenuParamValuePercent(500);
  param = new MenuParam(F("Fl. fade   "), value);
  params->set(parmBase + 2, param);
  value = new MenuParamValuePercent(500);
  param = new MenuParam(F("Fl. depth  "), value);
  params->set(parmBase + 3, param);
}

void setup() {
  // set output pins to output mode.  
  for (char chan = OUT_BASE; chan < OUT_BASE + 3; chan++) {
    OUT_DDR |= 1 << chan;
  }
  //analogReference(EXTERNAL);
  // Increase the analog sample rate to 76 kHz.
  ADCSRA &= ~( _BV(ADPS0) | _BV(ADPS1) ); // clear bits 0 and 1.
  ADCSRA |= _BV(ADPS2); // set bit 2.
  // Set up the timer.
  TCCR2A = _BV(WGM21); // normal mode
  TCCR2B = _BV(CS21); // 1/8 prescaler;
  OCR2A = 128; // interrupt at 15.625 Khz. (refresh rate = 60 Hz).
  TCNT2 = 0; // reset counter.
  // Enable interrupt on compare match
  TIMSK2 |= _BV(OCIE2A);
  // Start the USB Serial.
//  Serial.begin(115200);
  // set up the menu system.
  MenuModeList *modes;
  MenuMode *mode;
  MenuParamList *params;
  MenuParam *param;
  MenuParamValue *value;
  modes = new MenuModeList(3);
  params = new MenuParamList(7);
  value = new MenuParamValuePercent(1000);
  param = new MenuParam(F("Brightness"), value);
  params->set(0, param);
  value = new MenuParamValuePercent(0);
  param = new MenuParam(F("Saturation"), value);
  params->set(1, param);
  value = new MenuParamValuePercent(0);
  param = new MenuParam(F("Hue       "), value);
  params->set(2, param);
  addFlickerModes(params, FLICKER_BASE_SINGLE);
  value = new MenuParamValuePercent(0);
  mode = new MenuMode(F("Single Colour"), params, &setHSV);
  modes->set(0, mode);
  params = new MenuParamList(6);
  value = new MenuParamValuePercent(1000);
  param = new MenuParam(F("Brightness"), value);
  params->set(0, param);
  value = new MenuParamValuePercent(500);
  param = new MenuParam(F("Speed     "), value);
  params->set(1, param);
  addFlickerModes(params, FLICKER_BASE_FADE);
  mode = new MenuMode(F("Colour Fade  "), params, &colourCycle);
  modes->set(1, mode);
  params = new MenuParamList(4);
  value = new MenuParamValuePercent(1000);
  param = new MenuParam(F("Brightness"), value);
  params->set(0, param);
  value = new MenuParamValuePercent(0);
  param = new MenuParam(F("Smoothing "), value);
  params->set(1, param);
  value = new MenuParamValuePercent(0);
  param = new MenuParam(F("Peakiness "), value);
  params->set(2, param);
  value = new MenuParamValueOption(0, 6);
  value->setOption(0, F("rgb  "));
  value->setOption(1, F("rbg  "));
  value->setOption(2, F("grb  "));
  value->setOption(3, F("gbr  "));
  value->setOption(4, F("brg  "));
  value->setOption(5, F("bgr  "));
  param = new MenuParam(F("Mapping   "), value);
  params->set(3, param);
  mode = new MenuMode(F("Colour Organ "), params, &colourOrgan);
  modes->set(2, mode);
  // initialize the LCD library with the numbers of the pins
  lcd = new LiquidCrystal(7, 8, 9, 10, 11, 12);
  lcd->begin(16, 2);
  // set up rotary encoder.
  rot = new Rotary(2, 3);
  // initialise the menu system.
  /*lcd->setCursor(0, 0);
  lcd->print("top");
  lcd->setCursor(0, 1);
  lcd->print("bottom");*/
  menu = new LcdMenu(lcd, rot, A0, A1, 13, modes);
  menu->setMode(1);
  menu->print();
  attachInterrupt(digitalPinToInterrupt(2), encoderInterrupt, CHANGE);
  attachInterrupt(digitalPinToInterrupt(3), encoderInterrupt, CHANGE);
}

void loop() {
  static char doPrint = 0; // print menus when this is zero.
  static char chan = 0;
//  static int heartbeat = 0;
  while (!doLoop); // should break at every refresh.
  //PORTB |= 1 << DIAG_PIN - 8;
  doLoop = false;
  if (chan < 3) {
    chanVals[chan] = analogRead(chan + CHAN_BASE);
  } else {
  // read audio channels quickly
    menu->process(); // process encoder steps and set menu state.
    menu->runMode(); // run mode output callback.
    //setOutput(vals);
    doPrint++;
    if (doPrint > 5) {
      doPrint = 0;
      menu->print(); // print menu state.
    }
  }
  chan++;
  if (chan > 3) {
    chan = 0;
  }
/*  heartbeat++;
  heartbeat %= 1024;
  lcd->setCursor(15,0);
  if ((heartbeat == 0))  {
    lcd->write(0x6d);
  }
  if (heartbeat == 511) {
    lcd->write(0x20);
  }*/
//   PORTB &= ~(1 << DIAG_PIN - 8);
}

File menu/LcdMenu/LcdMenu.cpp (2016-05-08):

#include "LcdMenu.h"

void MenuParamValue::set(unsigned int valueArg) {
  value = valueArg;
}

unsigned int MenuParamValue::get() {
  return value;
}

MenuParamValuePercent::MenuParamValuePercent(unsigned int valueArg)  {
  value = valueArg;
}

void MenuParamValuePercent::step(char steps, unsigned int delay) {
  int accelSteps;
  unsigned int rate;
  char sign;
  if (steps >= 0) {
    accelSteps = steps;
    sign = 1;
  } else {
    accelSteps = -steps;
    sign = -1;
  }
  rate = delay / accelSteps;
  if (rate < 0x80) {
    accelSteps <<= ((0x80 - rate) >> 4);
  }
  accelSteps *= sign;
  if ((int)value + accelSteps < 0) {
    value = 0;
  } else if ((int)value + accelSteps > 1000) {
    value = 1000;
  } else {
    value += accelSteps;
  }
}

void MenuParamValuePercent::print(LiquidCrystal *lcd) {
  if (value < 1000) lcd->print(" ");
  if (value < 100) lcd->print(" ");
  lcd->print(value / 10);
  lcd->print(".");
  lcd->print(value % 10);
}

MenuParamValueOption::MenuParamValueOption(unsigned int valueArg, char lengthArg) {
  value = valueArg;
  length = lengthArg;
  options.reserve(length);
}

void MenuParamValueOption::step(char steps, unsigned int delay) {
  if ((int)value + steps < 0) {
    value = 0;
  } else if ((int)value + steps > length - 1) {
    value = length - 1;
  } else {
    value += steps;
  }
}

void MenuParamValueOption::print(LiquidCrystal *lcd) {
  lcd->print(options[value]);
}

void MenuParamValueOption::setOption(char index, const __FlashStringHelper *string) {
  options[index] = string;
}

MenuParam::MenuParam(const __FlashStringHelper *nameArg, MenuParamValue *valueArg) {
  name = nameArg;
  value = valueArg;
}

void MenuParam::print(LiquidCrystal * lcd) {
  lcd->print(name);
}

MenuParamValue *MenuParam::getValue() {
  return value;
}

MenuParamList::MenuParamList(unsigned char lengthArg) {
  length = lengthArg;
  items.reserve(lengthArg);
  current = 0;
}

void MenuParamList::set(unsigned char index, MenuParam *param) {
  items[index] = param;
}

MenuParam *MenuParamList::get(unsigned char index) {
  return items[index];
}

void MenuParamList::step(char steps) {
  if ((current + steps < length) && (current + steps >= 0)) current += steps;
}

MenuParam *MenuParamList::getCurrent() {
  return items[current];
}

MenuMode::MenuMode(const __FlashStringHelper* nameArg, MenuParamList *paramsArg, void (*cbArg)(MenuMode *)) {
  name = nameArg;
  params = paramsArg;
  callback = cbArg;
}

void MenuMode::runMode() {
  (*callback)(this);
}

void MenuMode::print(LiquidCrystal * lcd) {
  lcd->print(name);
}

MenuParamList * MenuMode::getParams() {
  return params;
}

MenuModeList::MenuModeList(unsigned char lengthArg) {
  length = lengthArg;
  items.reserve(lengthArg);
  current = 0;
}

void MenuModeList::set(unsigned char index, MenuMode *mode) {
  items[index] = mode;
}

void MenuModeList::setCurrent(unsigned char mode) {
  current = mode;
}

void MenuModeList::step(char steps) {
  if ((current + steps < length) && (current + steps >= 0)) current += steps;
}

MenuMode *MenuModeList::getCurrent() {
  return items[current];
}

LcdMenu::LcdMenu(LiquidCrystal *lcdArg, Rotary *rotArg, unsigned char modePinArg, unsigned char paramPinArg, unsigned char backlightPinArg, MenuModeList *modesArg) {
  lcd = lcdArg;
  rot = rotArg;
  modePin = modePinArg;
  paramPin = paramPinArg;
  backlightPin = backlightPinArg;
  modes = modesArg;
  visible = true;
  steps = 0;
  oldTime = 0;
  time = 0;
  pinMode(modePin, INPUT_PULLUP);
  pinMode(paramPin, INPUT_PULLUP);
  pinMode(backlightPin, OUTPUT);
}

void LcdMenu::readEncoder() {
  if (!visible) return;
  switch (rot->process()) {
    case DIR_CW:
      steps++;
      break;
    case DIR_CCW:
      steps--;
      break;
  }
}

void LcdMenu::process() {
  unsigned int delay;
  if (!visible) return;
  time = millis();
  if ((unsigned long)(time - oldTime) >= 0x7fff) {
    oldTime = (unsigned long)(time - 0x7fff); // don't count very long delays.
  }
  delay = (unsigned int)(time - oldTime);
  if (steps != 0) {
    if (! digitalRead(modePin)) {
      modes->step(steps);
    } else if (! digitalRead(paramPin)) {
      modes->getCurrent()->getParams()->step(steps);
    } else {
      modes->getCurrent()->getParams()->getCurrent()->getValue()->step(steps, (unsigned int)delay);
    }
  steps = 0;
  oldTime = time;
  }
}

void LcdMenu::print() {
  if (!visible) return;
  lcd->setCursor(0, 0);
  modes->getCurrent()->print(lcd);
  lcd->setCursor(0, 1);
  modes->getCurrent()->getParams()->getCurrent()->print(lcd);
  lcd->setCursor(11, 1);
  modes->getCurrent()->getParams()->getCurrent()->getValue()->print(lcd);
}


void LcdMenu::runMode() {
  modes->getCurrent()->runMode();
}

void LcdMenu::setMode(unsigned char mode) {
  modes->setCurrent(mode);
}

void LcdMenu::setVisible(bool visArg) {
  if (visArg) {
    visible = true;
    digitalWrite(backlightPin, LOW);
    print();
  } else {
    visible = false;
    digitalWrite(backlightPin, HIGH);
    lcd->clear();
  }
}

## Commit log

2012-10-30 added mode cycling switch
2016-04-26 added directory with pcb files.
    [audio-process.sch, bill-of-materials.ods, colour-organ.sch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]
2016-10-22 working on finding components for parts
    [audio-process.sch, bill-of-materials.ods, colour-organ.sch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]
2016-10-23 finished choosing components for main board
    [audio-process.sch, colour-organ.sch, controls.sch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]
2016-10-23 found components for controls board
    [controls.sch]
2018-10-16 misc. changes
    [audio-process.sch, bill-of-materials.ods, colour-organ.sch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]
